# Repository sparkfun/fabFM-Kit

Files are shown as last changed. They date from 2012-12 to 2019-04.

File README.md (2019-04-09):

**NOTE:** *This product has been retired from our catalog. If you are looking for more up-to-date info, please check out some of these resources to see how other users are still hacking and improving on this product.*
* *[SparkFun Forum](https://forum.sparkfun.com/)*
* *[IRC Channel](https://www.sparkfun.com/news/263)*

FabFM Radio Kit
===============

[FabFM Radio Kit  
*FabFM Radio Kit (KIT-11043)*](https://www.sparkfun.com/products/11043)

The FabFM is a stylish FM radio kit that can be built with just basic soldering tools. The PCB is all PTH, meaning that even a beginner solderer can put this kit together with a little time. The wooden, laser cut frame doesn't take any tools or glue to put together, each part press-fits into another. Once assembled the FabFM Radio Kit produces a fully functioning, old-school style FM radio.

[*See the wiki for assembly instuctions.*](https://github.com/sparkfun/fabFM-Kit/wiki)

Repository Contents
-------------------

* **/enclosure** - Vector files for the enclosure
* **/firmware** - Arduino sketch that is loaded onto the ATMega328
* **/hardware** - Eagle PCB layout files

License Information
-------------------

All contents of this repository are released under [Creative Commons Share-alike 3.0](http://creativecommons.org/licenses/by-sa/3.0/).

Authors: Aaron Weiss @ SparkFun Electonics, Original Design by David Mellis and Dana Gordon

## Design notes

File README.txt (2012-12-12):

Fab-FM-Kit
==========

*See the wiki for assembly instuctions.*
https://github.com/sparkfun/fabFM-Kit/wiki

Hardware contains the Eagle PCB layout files and the firmware contains the arduino sketch that is loaded onto the atmega328.

License
=====

Creative Commons Attribution-ShareAlike
http://creativecommons.org/licenses/by-sa/3.0/

Authors: Aaron Weiss @ SparkFun Electonics, Original Design by David Mellis and Dana Gordon

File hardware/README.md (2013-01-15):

These are the Eagle PCB files for the fabfm.

See the commit comments for version information.

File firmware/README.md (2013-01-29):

This is the example Arduino sketch that runs on the atmega328. Use Arduino Pro (3.3V, 8HMz) for the board selection in arduino. 

DO NOT use the 'Burn Bootloader' command in Arduino, since those use different fuses.

The Si4703 Library needs to be used and can be found [here](https://dlnmh9ip6v2uc.cloudfront.net/tutorialimages/fabfm/Si4703_Breakout.zip).

For more detailed instructions see the [modification section](https://github.com/sparkfun/fabFM-Kit/wiki/Modifications) and (scroll down).

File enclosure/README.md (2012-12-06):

These are the enclosure files in svg and pdf format. They were created to be used on a laser cutter with a 24x18 inch operating area. The veneer template is optional and can either be created with a laser cutter or just some scissors.

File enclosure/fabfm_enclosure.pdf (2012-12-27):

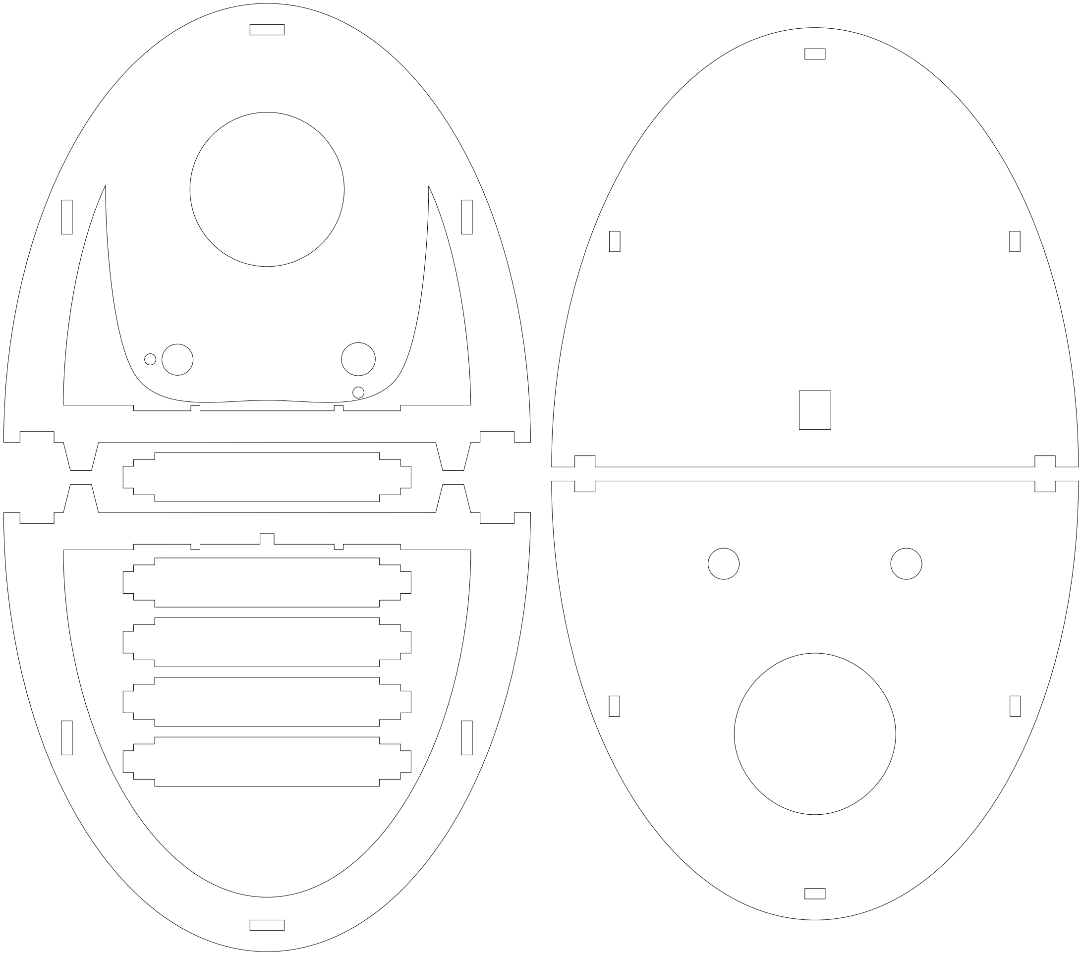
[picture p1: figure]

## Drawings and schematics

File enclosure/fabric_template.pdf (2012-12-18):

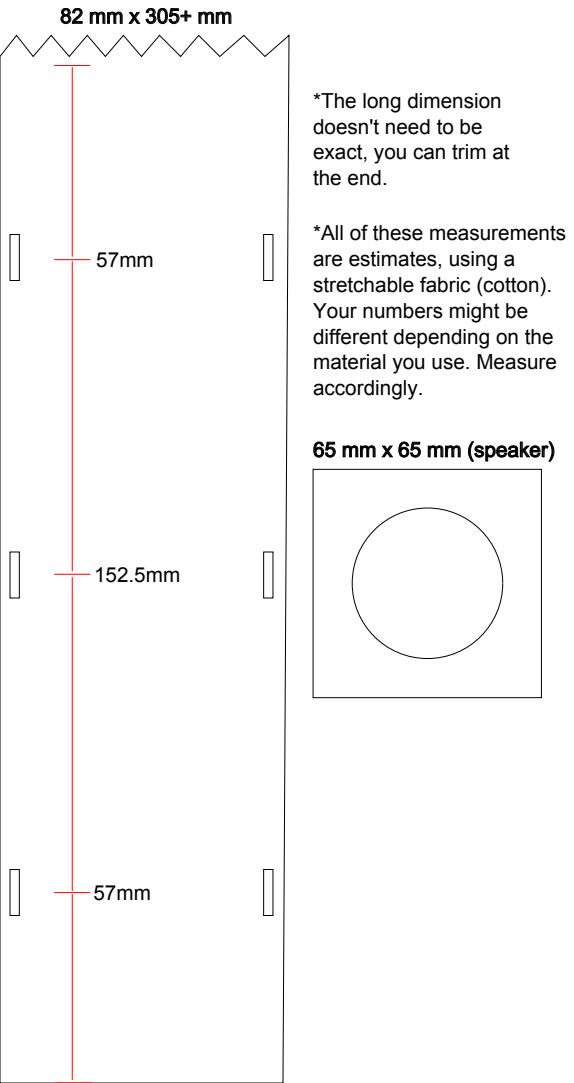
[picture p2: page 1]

*The long dimension
doesn't need to be
exact, you can trim at
the end.

*All of these measurements
are estimates, using a
stretchable fabric (cotton).
Your numbers might be
different depending on the
material you use. Measure
accordingly.

65 mm x 65 mm (speaker)

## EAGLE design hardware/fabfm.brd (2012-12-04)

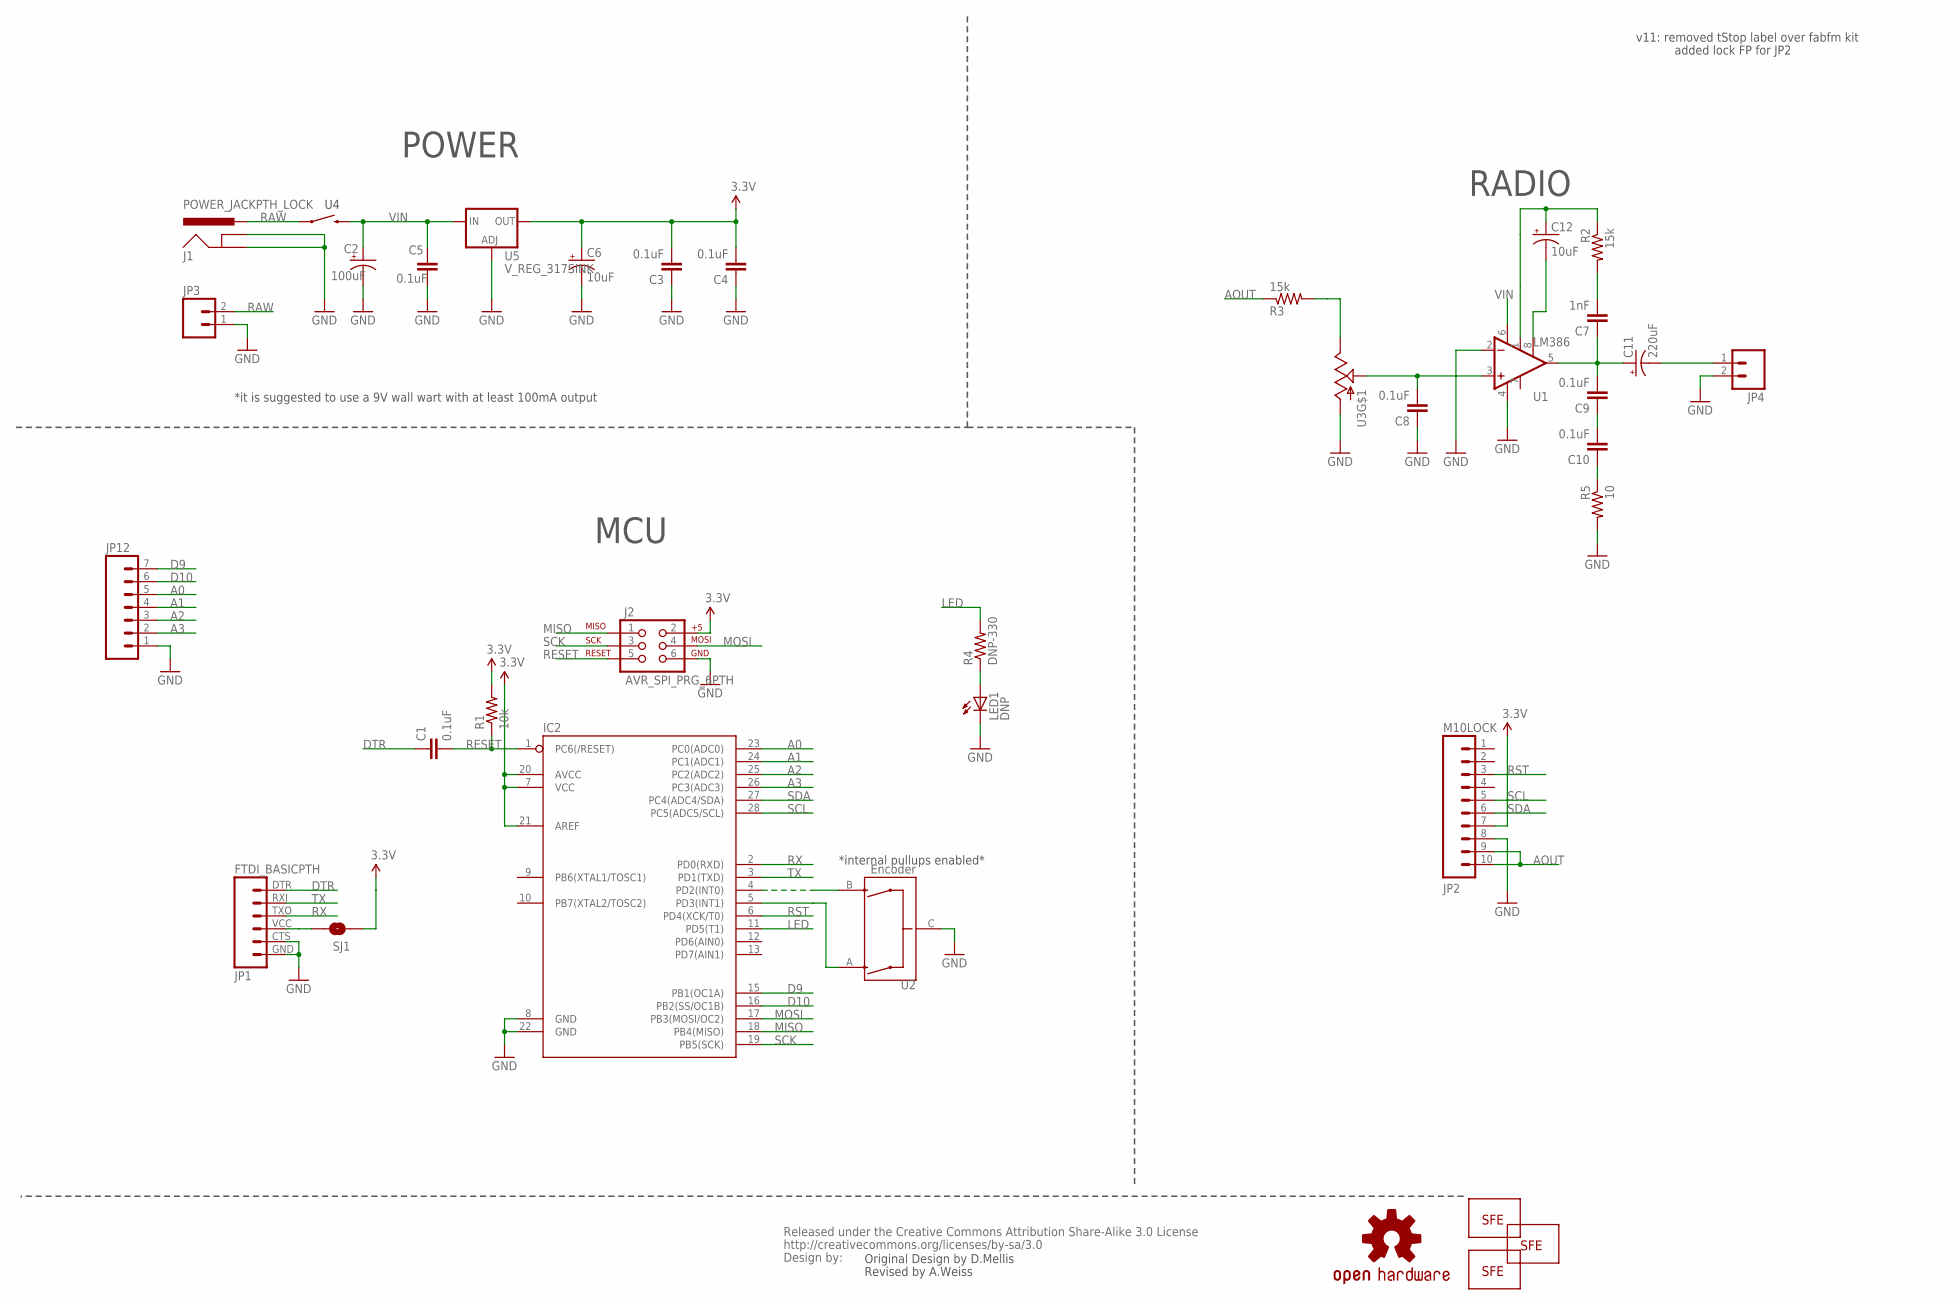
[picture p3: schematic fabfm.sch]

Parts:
C1, C3, C4, C5, C8, C9, C10: 0.1uF; CAP-PTH-SMALL-KIT
C2: 100uF; CPOL-RADIAL-100UF-25V
C6, C12: 10uF; CPOL-RADIAL-10UF-25V
C7: 1nF; CAP-PTH-SMALL-KIT
C11: 220uF; CPOL-RADIAL-100UF-25V
IC2: ATMEGA328P_PDIP_EZ_PB0; DIL28-EZ-PB0
J1: POWER_JACKPTH_LOCK; POWER_JACK_PTH_LOCK
J2: AVR_SPI_PRG_6PTH; 2X3
JP1: FTDI_BASICPTH; FTDI_BASIC
JP2: M10LOCK; 1X10_LOCK
JP3: M02PTH; 1X02
JP4: M02PTH4; 1X02_XTRA_BIG
JP8: LOGO-SFESK; SFE-LOGO-FLAME
JP9, JP11: LOGO-SFENEW; SFE-NEW-WEBLOGO
JP12: M07; 1X07
LED1: DNP; LED3MM
R1: 10k; AXIAL-0.4
R2, R3: 15k; AXIAL-0.4
R4: DNP-330; AXIAL-0.4
R5: 10; AXIAL-0.4
SJ1: SOLDERJUMPERNO; SJ_2S-NO
U1: LM386; DIP08
U2: Encoder; ENCODER-16MM-QUAD
U3: POT_SWITCHPOT_PTH_SWITCH; POT_PTH_SWITCH
U5: V_REG_317SINK; TO220-ADJ
U$1: OSHW-LOGOS; OSHW-LOGO-S
U$2: CREATIVE_COMMONS

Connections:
3.3V: C3.2, C4.2, C6.1 (+), IC2.7 (VCC), IC2.20 (AVCC), IC2.21 (AREF), J2.2, JP2.7, R1.P$2 (2), SJ1.1, U5.OUT
A: IC2.5 (PD3(INT1)), U2.A
A0: IC2.23 (PC0(ADC0)), JP12.5
A1: IC2.24 (PC1(ADC1)), JP12.4
A2: IC2.25 (PC2(ADC2)), JP12.3
A3: IC2.26 (PC3(ADC3)), JP12.2
AOUT: JP2.9, JP2.10, R3.P$1 (1)
B: IC2.4 (PD2(INT0)), U2.B
D9: IC2.15 (PB1(OC1A)), JP12.7
D10: IC2.16 (PB2(SS/OC1B)), JP12.6
DTR: C1.1, JP1.DTR (1)
GND: C2.2 (-), C3.1, C4.1, C5.1, C6.2 (-), C8.1, IC2.8 (GND), IC2.22 (GND), J1.GND, J1.GNDBREAK, J2.6, JP1.CTS (5), JP1.GND (6), JP2.8, JP3.1, JP4.2, JP12.1, LED1.K (C), R5.P$2 (2), U1.2 (-IN), U1.4 (V-), U2.C, U3.1 (A), U5.ADJ
LED: IC2.11 (PD5(T1)), R4.P$2 (2)
MISO: IC2.18 (PB4(MISO)), J2.1
MOSI: IC2.17 (PB3(MOSI/OC2)), J2.4
unnamed: LED1.A, R4.P$1 (1)
unnamed: C8.2, U1.3 (+IN), U3.2 (S)
unnamed: C7.1, C9.2, C11.1 (+), U1.5 (OUT)
unnamed: C12.1 (+), R2.P$1 (1), U1.1 (GAIN)
unnamed: C11.2 (-), JP4.1
unnamed: C9.1, C10.2
unnamed: C10.1, R5.P$1 (1)
unnamed: C12.2 (-), U1.8 (GAIN)
unnamed: C7.2, R2.P$2 (2)
unnamed: R3.P$2 (2), U3.3 (E)
unnamed: JP1.VCC (4), SJ1.2
RAW: J1.PWR, JP3.2, U3.S1 (1)
RESET: C1.2, IC2.1 (PC6(/RESET)), J2.5, R1.P$1 (1)
RST: IC2.6 (PD4(XCK/T0)), JP2.3
RX: IC2.2 (PD0(RXD)), JP1.TXO (3)
SCK: IC2.19 (PB5(SCK)), J2.3
SCL: IC2.28 (PC5(ADC5/SCL)), JP2.5
SDA: IC2.27 (PC4(ADC4/SDA)), JP2.6
TX: IC2.3 (PD1(TXD)), JP1.RXI (2)
VIN: C2.1 (+), C5.2, U1.6 (V+), U3.S2 (2), U5.IN

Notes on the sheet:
Original Design by D.Mellis
POWER
MCU
RADIO
Revised by A.Weiss
*internal pullups enabled*
*it is suggested to use a 9V wall wart with at least 100mA output
v11: removed tStop label over fabfm kit
added lock FP for JP2

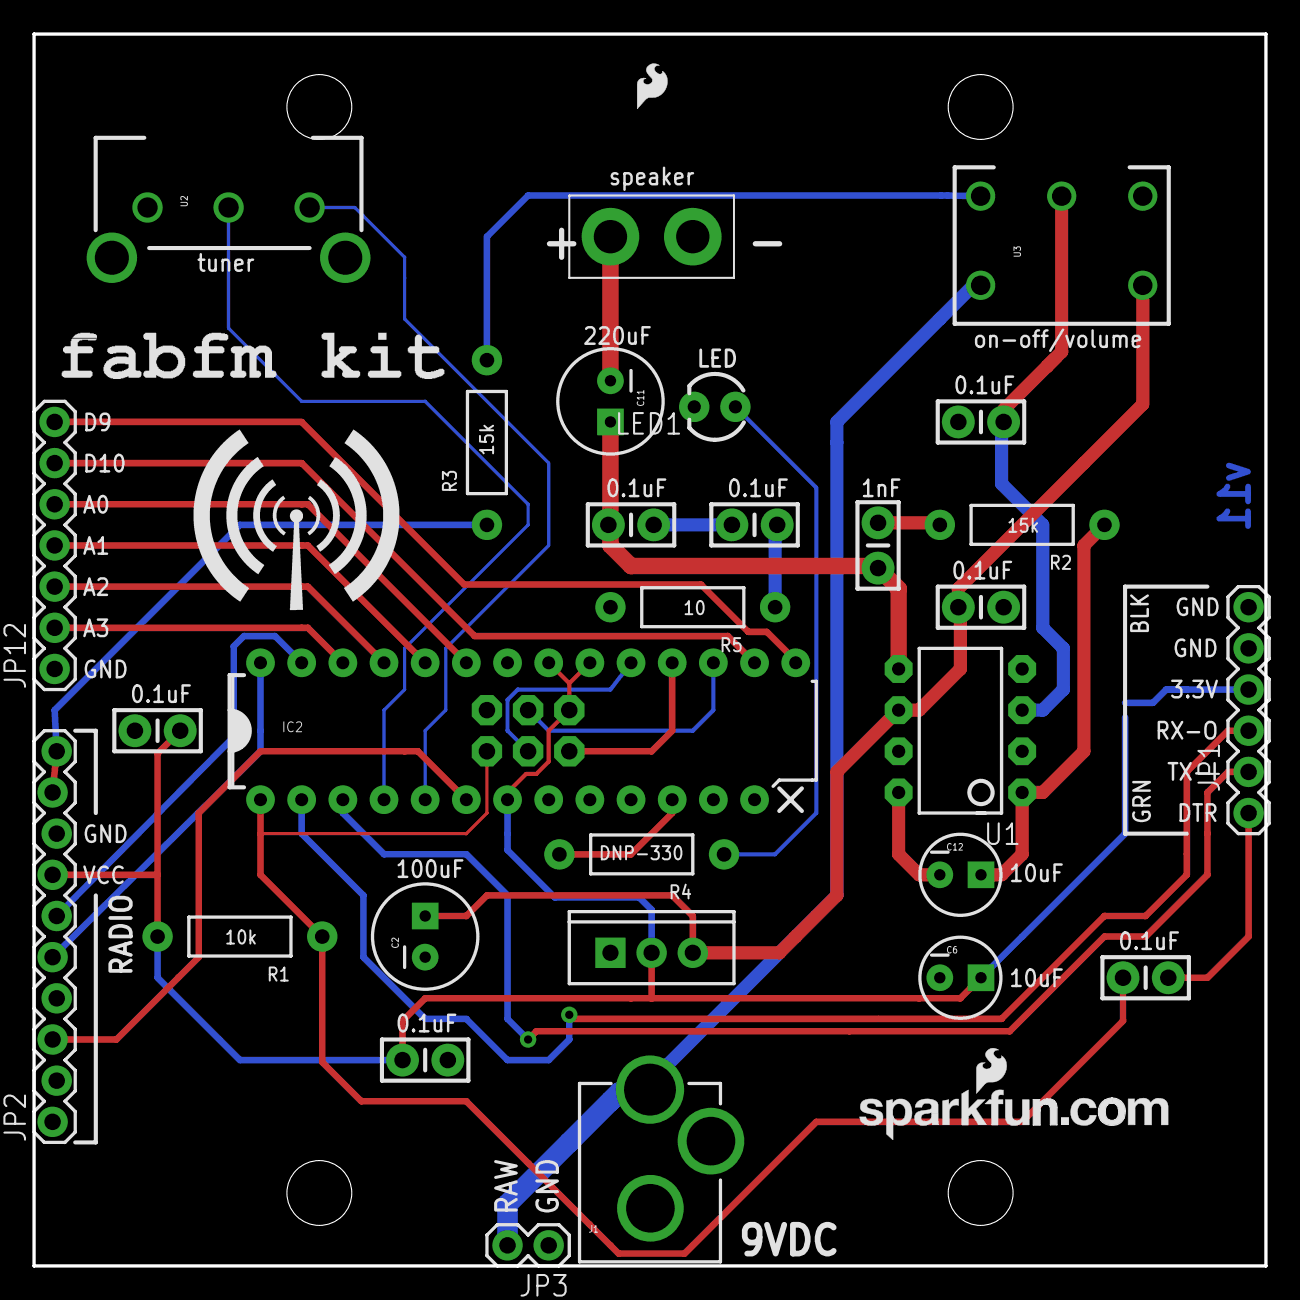
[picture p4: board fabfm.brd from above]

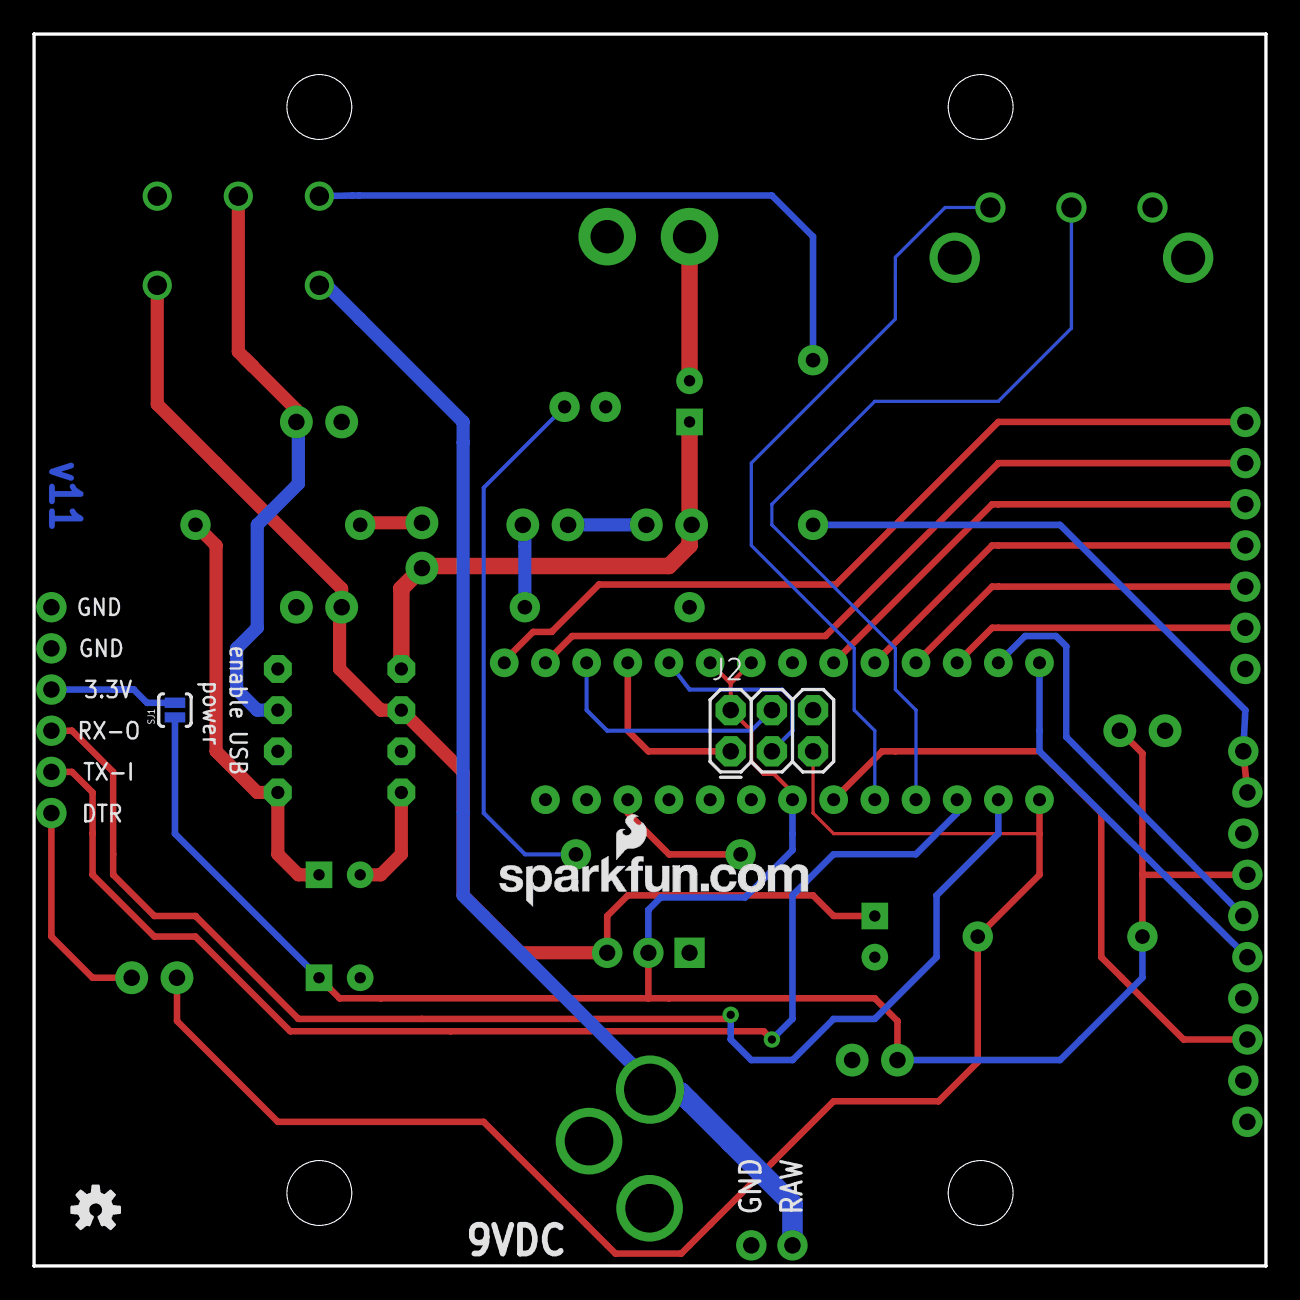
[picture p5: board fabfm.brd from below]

Board: 2 copper layers, 76.0 x 76.0 mm, 36 parts (4 on the bottom side), 35 nets.

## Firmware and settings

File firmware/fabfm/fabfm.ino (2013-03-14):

///////////////////////////////////////////////////////////////////
 /*  FabFm Firmware v11 
 *   
 *   Aaron Weiss, SparkFun 2012
 *   license: beerware
 *   
 *   Description:
 *   This is example code for the FamFM radio kit. The hardware
 *   mimics an Arduino Pro (3.3V, 8MHz) and has an FTDI header 
 *   to load Arduino sketches. The hardware includes the Si4703
 *   FM radio module to find the stations along with an op-amp 
 *   and speaker for the audio. The unit has a potentiometer
 *   with a switch for power and volume control, and a rotary
 *   encoder to tune the stations. The unit displays the radio
 *   station over a serial terminal at 115200 and also saves the 
 *   station on subsequent power ups. 
 *
 *   The Si4703 libarary needs to be used:
 *   http://dlnmh9ip6v2uc.cloudfront.net/datasheets/BreakoutBoards/Si4703_Breakout-Arduino_1_compatible.zip
 *   
 *   Operation:
 *   -Power switch and volume are on the left, tuner is on the right.
 *   -The board must be powered with a switch mode 9V DC wall wart.
 *   -Each click will increase/decrease station by 0.2MHz 
 *   -The LED blinks for every step
 */   
///////////////////////////////////////////////////////////////////

// Libraries needed
// Si4703 lib: See above
#include <Si4703_Breakout.h>
// included with Arduino
#include <Wire.h>
// included with Arduino
#include <EEPROM.h>

// Global Constants (defines): these quantities don't change
const int resetPin = 4; //radio reset pin
const int SDIO = A4; //radio data pin
const int SCLK = A5; //radio clock pin
const int encoderPin1 = 2; // encoder pin 1
const int encoderPin2 = 3; // encoder pin 2
const int LED = 5; //optional LED pin

// Global Variables: these quantities change
int channel;
int rotate;

//Volatile variables are needed if used within interrupts
volatile int lastEncoded = 0;
volatile long encoderValue = 0;

volatile int goodEncoderValue;
volatile boolean updateStation = false;

const boolean UP = true;
const boolean DOWN = false;
volatile boolean stationDirection;

// You must call this to define the pins and enable the FM radio 
// module.
Si4703_Breakout radio(resetPin, SDIO, SCLK);

// Arduino setup function
void setup()
{
  // both pins on the rotary encoder are inputs and pulled high
  pinMode(encoderPin1, INPUT_PULLUP);
  pinMode(encoderPin2, INPUT_PULLUP);
  
  // LED pin is output
  pinMode(LED, OUTPUT);
  
  // load saved station into channel variable
  read_channel_from_EEPROM();
  
  // start radio module
  radio.powerOn(); // turns the module on
  radio.setChannel(channel); // loads saved channel
  radio.setVolume(15); //Loudest volume setting
  digitalWrite(LED, HIGH); //turn LED ON
  
  //start serial and print welcome screen with station number
  Serial.begin(115200); //must use a fast baud to prevent errors
  Serial.print("\nfab fm: ");
  Serial.println(channel, DEC);

  //call updateEncoder() when any high/low changed seen
  //on interrupt 0 (pin 2), or interrupt 1 (pin 3) 
  attachInterrupt(0, updateEncoder, CHANGE); 
  attachInterrupt(1, updateEncoder, CHANGE);
}

// Arduino main loop
void loop()
{
  //Wait until the interrupt tells us to update the station
  if(updateStation)
  {
    digitalWrite(LED, LOW);

    if(stationDirection == UP)
    {
      //Serial.print("Up ");
      channel += 2; //Channels change by 2 (975 to 973)
    }
    else if(stationDirection == DOWN)
    {
      //Serial.print("Down ");
      channel -= 2; //Channels change by 2 (975 to 973)
    }
    
    //Catch wrap conditions
    if(channel > 1079) channel = 875;
    if(channel < 875) channel = 1079;

    Serial.println(channel, DEC); // print channel number

    radio.setChannel(channel); //Goto the new channel
    save_channel(); // save channel to EEPROM

    digitalWrite(LED, HIGH);
    
    updateStation = false; //Clear flag
  }

  // You can put any additional code here, but keep in mind, 
  // the encoder interrupt is running in the background
}

// NAME: save_channel() 
// DEFINITION: splits the channel variable into two separate bytes, 
// then loads each value into one 8-bit EEPROM location
void save_channel()
{
  int msb = channel >> 8; // move channel over 8 spots to grab MSB
  int lsb = channel & 0x00FF; // clear the MSB, leaving only the LSB
  EEPROM.write(1, msb); // write each byte to a single 8-bit position
  EEPROM.write(2, lsb);
}

// NAME: read_channel_from_EEPROM() 
// DEFINITION: reads the two saved 8-bit values, that defines the 
// channel, and concatenates them together to form a 16-bit number 
void read_channel_from_EEPROM()
{
  int msb = EEPROM.read(1); // load the msb into one 8-bit register
  int lsb = EEPROM.read(2); // load the lsb into one 8-bit register
  msb = msb << 8; // shift the msb over 8 bits
  channel = msb|lsb; // concatenate the lsb and msb
}

//This is the interrupt that reads the encoder
//It set the updateStation flag when a new indent is found 
//Note: The encoder used on the FabFM has a mechanical indent every four counts
//So most of the time, when you advance 1 click there are four interrupts
//But there is no guarantee the user will land neaty on an indent, so this code cleans up the read
//Modified from the bildr article: http://bildr.org/2012/08/rotary-encoder-arduino/
void updateEncoder()
{
  int MSB = digitalRead(encoderPin1); //MSB = most significant bit
  int LSB = digitalRead(encoderPin2); //LSB = least significant bit

  int encoded = (MSB << 1) |LSB; //converting the 2 pin value to single number
  int sum  = (lastEncoded << 2) | encoded; //adding it to the previous encoded value

  if(sum == 0b1101 || sum == 0b0100 || sum == 0b0010 || sum == 0b1011)
  {
    stationDirection = DOWN; //Counter clock wise
    encoderValue--;
  }
  if(sum == 0b1110 || sum == 0b0111 || sum == 0b0001 || sum == 0b1000)
  {
    stationDirection = UP; //Clock wise
    encoderValue++;
  }

  lastEncoded = encoded; //store this value for next time

  //Wait until we are more than 3 ticks from previous used value
  if(abs(goodEncoderValue - encoderValue) > 3)
  {
    //The user can sometimes miss an indent by a count or two
    //This logic tries to correct for that
    //Remember, interrupts are happening in the background so encoderValue can change 
    //throughout this code

    if(encoderValue % 4 == 0) //Then we are on a good indent
    {
      goodEncoderValue = encoderValue; //Remember this good setting
    }
    else if( abs(goodEncoderValue - encoderValue) == 3) //The encoder is one short
    {
      if(encoderValue < 0) goodEncoderValue = encoderValue - 1; //Remember this good setting
      if(encoderValue > 0) goodEncoderValue = encoderValue + 1; //Remember this good setting
    }
    else if( abs(goodEncoderValue - encoderValue) == 5) //The encoder is one too long
    {
      if(encoderValue < 0) goodEncoderValue = encoderValue + 1; //Remember this good setting
      if(encoderValue > 0) goodEncoderValue = encoderValue - 1; //Remember this good setting
    }

    updateStation = true;
  }
}

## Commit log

2012-10-23 v10
    first
    [fabfm.brd, fabfm.sch]
2012-11-29 added enclosure files
    production grade
2012-12-04 v11
    -fixed silk mistake
    -added locking FP for radio module
    [fabfm.brd, fabfm.sch]
2012-12-27 enclosure strut openings increased
    to account for changes in wood thickness, I increased the size of all of
    the holes the struts fit into
2013-03-11 Added interrupt support for encoder.
    This fixes the four click reading of the encoder. The encoder is now
    correctly read every click. Also removed link to dropbox copy of library
    (does not compile).
    [fabfm.ino]
2013-03-11 Change to direct channel contron.
    This removes seek and replaces it with direct channel control. This is
    the type of control I would expect from an analog radio/analog knob. I
    find it is easier to find the station that I am looking for. Currently
    steps 200kHz so works with US only.
    [fabfm.ino]
2013-03-14 firmware changes
    changed version txt in code, commented out up and down print statements
2013-05-01 proto files for collaborator
    -collabs version number is v2
    -needs aesthetic cleanup
    [PumpSpark.brd, PumpSpark.sch, fabfm.brd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]
2013-05-01 Revert "proto files for collaborator"
    This reverts commit 7e2bf316ebb5f1758cee9bcbaeecd761c46ab435.
    [PumpSpark.brd, PumpSpark.sch, fabfm.brd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]

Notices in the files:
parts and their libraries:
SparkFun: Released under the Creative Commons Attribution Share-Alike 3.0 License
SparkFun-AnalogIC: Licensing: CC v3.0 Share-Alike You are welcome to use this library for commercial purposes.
